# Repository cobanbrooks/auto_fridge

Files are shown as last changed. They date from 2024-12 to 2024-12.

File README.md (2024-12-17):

Automated fridge that is opened/closed by a linear actuator controlled by an arduino. This repo should be most of what you need to build one.

The arduino recieves input from two 5V I/O signal wires. When signal 1 is HIGH and  signal 2 is LOW, the actuator extends. When signal 1 is LOW and signal 2 is HIGH, the circuit reverses the polarity of the voltage to the actuator and it retracts.

It is important to use a relay with this design as the actuator is powered by 12V and the arduino can only output 5V. So, the 5V signal from the arduino switches the relay which then draws 12V from the wall to power the actuator.

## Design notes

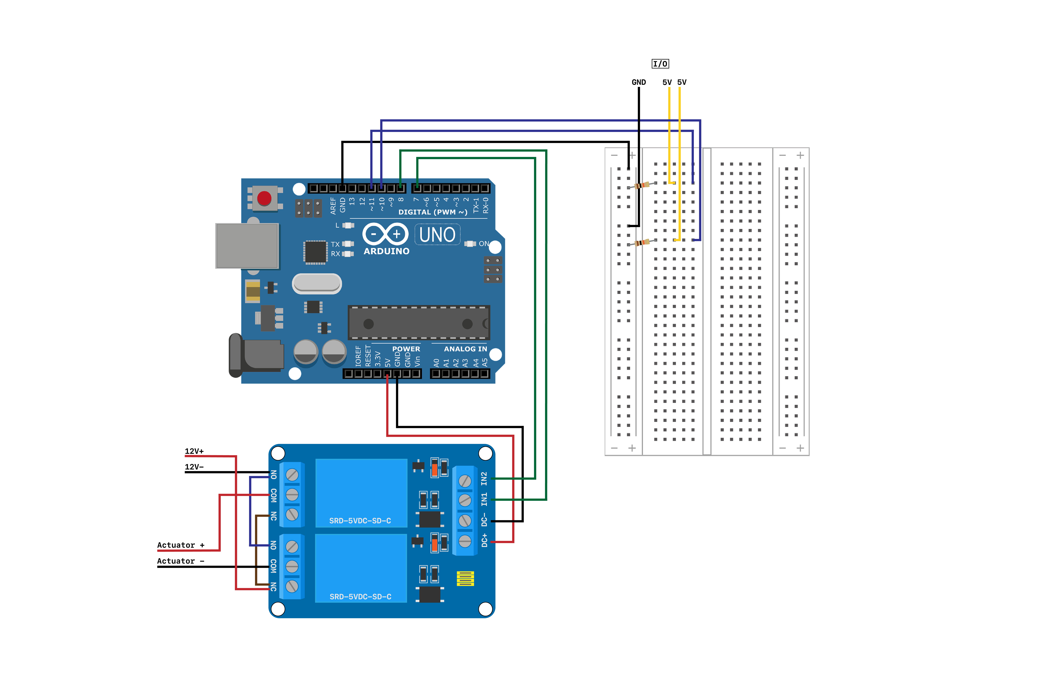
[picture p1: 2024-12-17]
fridge_circuit_diagram.png

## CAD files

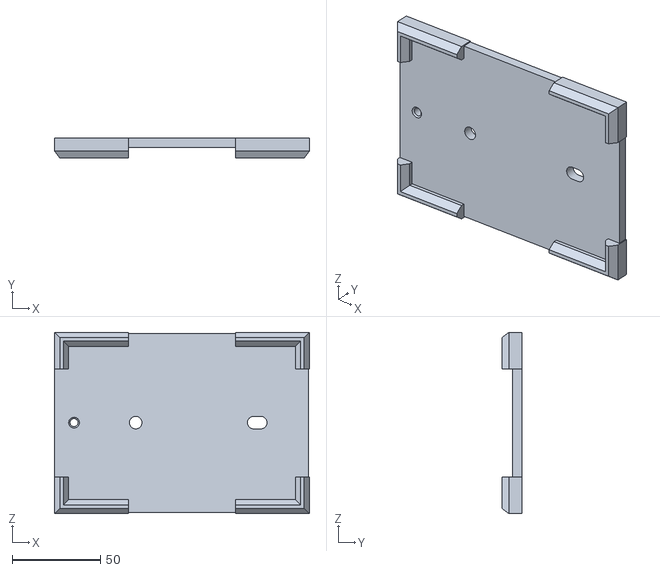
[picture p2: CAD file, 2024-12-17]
3dprinting_files/plate_offset_final.stl
144.8 x 11.3 x 103.0

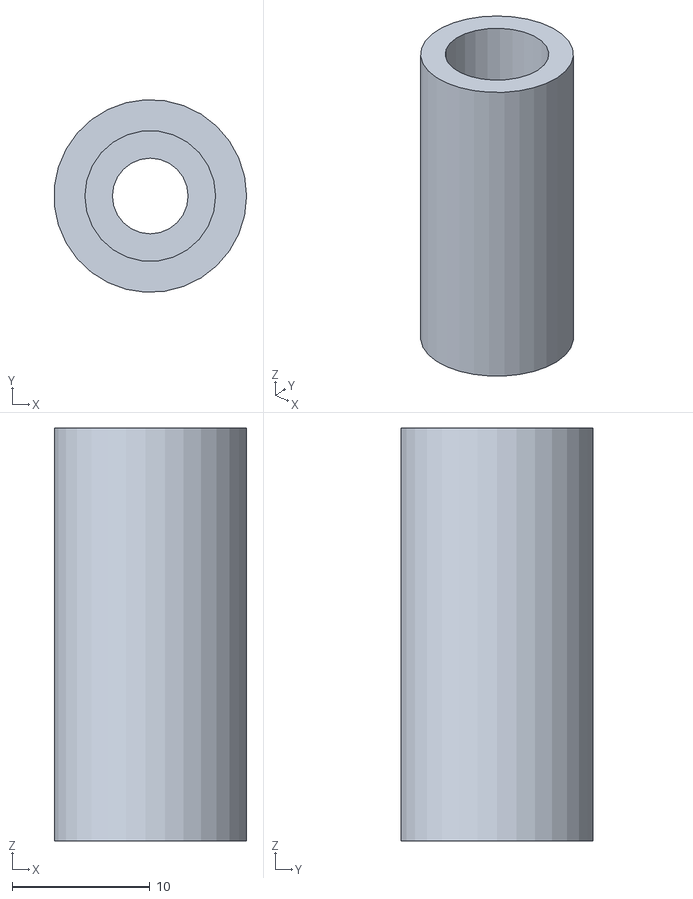
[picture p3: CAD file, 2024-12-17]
3dprinting_files/minifridge_mounting_post.stl
14.0 x 14.0 x 30.0

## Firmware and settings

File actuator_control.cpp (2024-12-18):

// Pin definitions
const int RELAY_IN1 = 8;      // First relay control pin
const int RELAY_IN2 = 7;      // Second relay control pin
const int IO_SIGNAL1 = 10;     // First I/O input from liquid handler
const int IO_SIGNAL2 = 11;     // Second I/O input from liquid handler

// Timing constants
const int RELAY_DELAY = 50;   // Delay between relay switching to prevent shorts

void setup() {
  // Configure relay control pins as outputs
  pinMode(RELAY_IN1, OUTPUT);
  pinMode(RELAY_IN2, OUTPUT);

  // Configure I/O signal pins as inputs
  pinMode(IO_SIGNAL1, INPUT);
  pinMode(IO_SIGNAL2, INPUT);

  // Initialize relays to OFF state
  digitalWrite(RELAY_IN1, HIGH);  // Relays are typically active LOW
  digitalWrite(RELAY_IN2, HIGH);
}

void loop() {
  // Read I/O signals
  int signal1 = digitalRead(IO_SIGNAL1);
  int signal2 = digitalRead(IO_SIGNAL2);

  // Safety check - make sure both signals aren't active
  if (signal1 == HIGH && signal2 == HIGH) {
    // Error condition - turn everything off
    digitalWrite(RELAY_IN1, HIGH);
    digitalWrite(RELAY_IN2, HIGH);
    return;
  }

  // Direction 1 - First signal active
  if (signal1 == HIGH && signal2 == LOW) {
    digitalWrite(RELAY_IN2, HIGH);  // Make sure other relay is off first
    delay(RELAY_DELAY);            // Brief delay to prevent shorts
    digitalWrite(RELAY_IN1, LOW);   // Activate first relay
  }
  // Direction 2 - Second signal active
  else if (signal2 == HIGH && signal1 == LOW) {
    digitalWrite(RELAY_IN1, HIGH);  // Make sure other relay is off first
    delay(RELAY_DELAY);            // Brief delay to prevent shorts
    digitalWrite(RELAY_IN2, LOW);   // Activate second relay
  }
  // No signals active - stop movement
  else {
    digitalWrite(RELAY_IN1, HIGH);
    digitalWrite(RELAY_IN2, HIGH);
  }
}

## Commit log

2024-12-16 arduino code for actuator control
2024-12-17 3d printing files for 96-well plate trays
    [minifridge_mounting_post.stl, plate_offset_final.stl]
2024-12-17 wiring diagram for actuator circuit
2024-12-17 fixed wiring
2024-12-17 signal pin configuration
2024-12-18 Pin configuration
